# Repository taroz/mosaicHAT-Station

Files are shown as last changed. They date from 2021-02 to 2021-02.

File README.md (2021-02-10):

# mosaicHAT-Station
## Introduction
- [**mosaicHAT**](https://github.com/septentrio-gnss/mosaicHAT) + **GNSS antenna** + **Raspberry Pi** + **Touch display** + **Battery** + **Case**
- We use [Septentrio's mosaic-X5](https://www.septentrio.com/en/products/gnss-receivers/rover-base-receivers/receivers-module/mosaic) GNSS module which is a **low-cost** and **survey-grade** GNSS receiver
- This project is inspired by [mosaicHAT](https://github.com/septentrio-gnss/mosaicHAT) and extends it further. Thanks to the wonderful project [mosaicHAT](https://github.com/septentrio-gnss/mosaicHAT)!
- License: [Creative Commons Attribution Share-Alike License](https://creativecommons.org/licenses/by-sa/4.0/). and [Open Source HW](https://www.oshwa.org/definition/)  
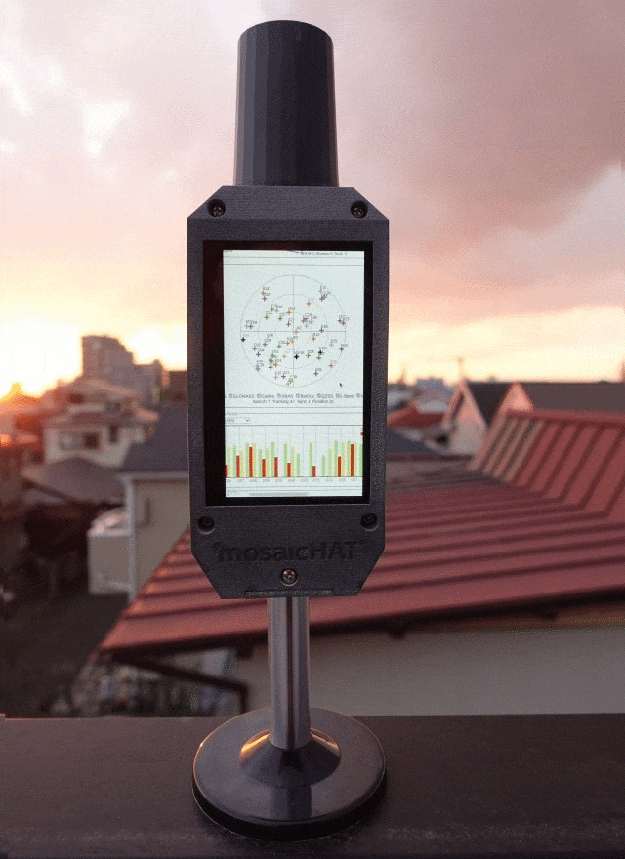
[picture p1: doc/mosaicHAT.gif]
 

## Features
- mosaicHAT Station has a touch display to display a web user interface of mosaic-X5 receiver. We can easily operate, monitor, and control the GNSS receiver.
- Compared to the original [mosaicHAT](https://github.com/septentrio-gnss/mosaicHAT), we added micro SD card and a log button, so you can easily store GNSS data as a GNSS reference or rover station.  
  [](https://www.youtube.com/watch?v=CmkE35LLup8)

## Board
- The design of the board is based on the original [mosaicHAT](https://github.com/septentrio-gnss/mosaicHAT).
- [KiCAD files](./board/KiCAD) and [PCB](./board/KiCAD/pcb)
- Micro SD card and log button have been added for data logging capability
- Bill of Materials (BOM) is [here](./board/mosaicHAT_BOM.xlsx)                                 
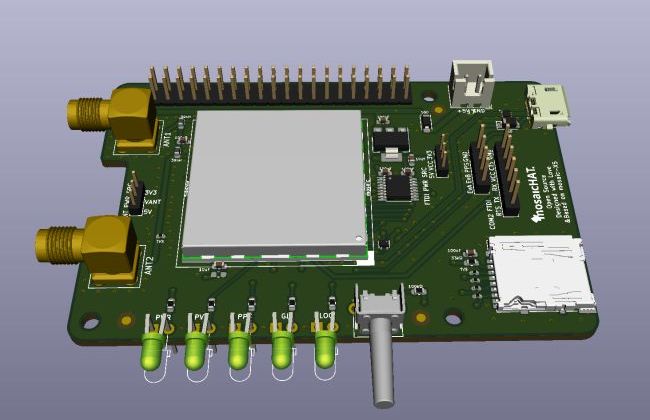
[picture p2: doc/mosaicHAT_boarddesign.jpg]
  

## Case
- You can create using 3D printer (STL data is [here](./case))
  - I used 3D printing service (by [Shapeways](https://www.shapeways.com/shops/tarosuzuki)) 
- A 5/8 nut can be fixed on the case, which can be attached to a pole or antenna mount for GNSS surveying.  
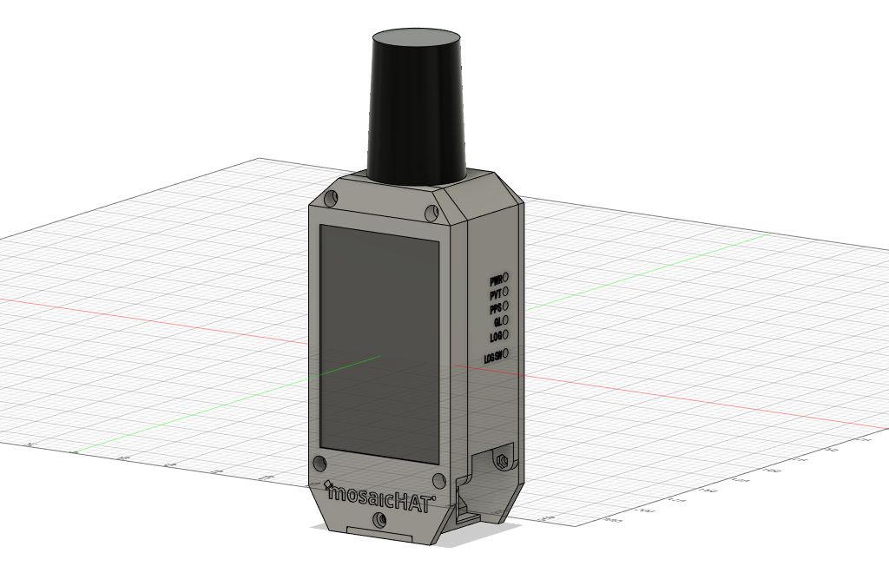
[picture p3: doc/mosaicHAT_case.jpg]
 

## How to assemble
- Parts list is [here](./case/parts_list.xlsx)  
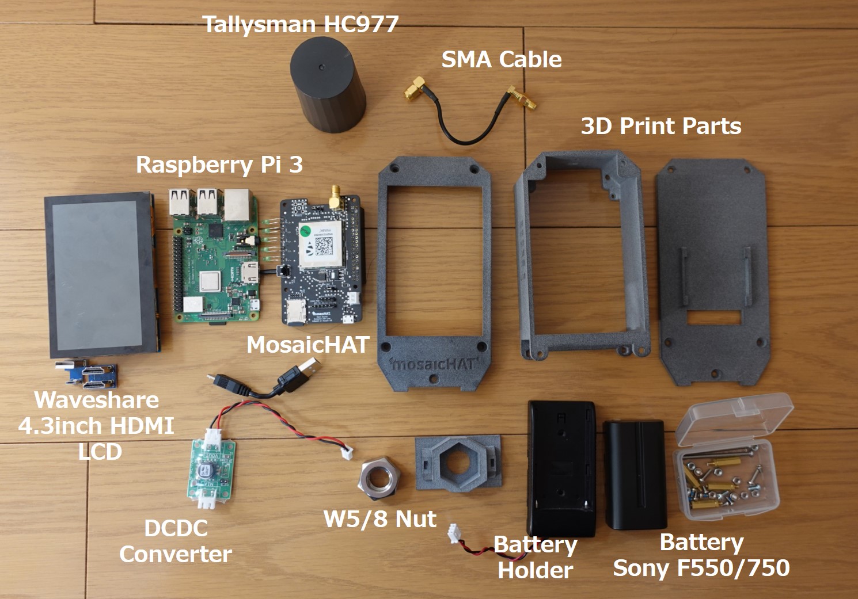
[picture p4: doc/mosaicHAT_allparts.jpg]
<p>

1. Mount the Raspberry Pi on the touch display. Then mount the mosaicHAT on the Rasberry Pi using the M2.5 18mm spacers and screws.   
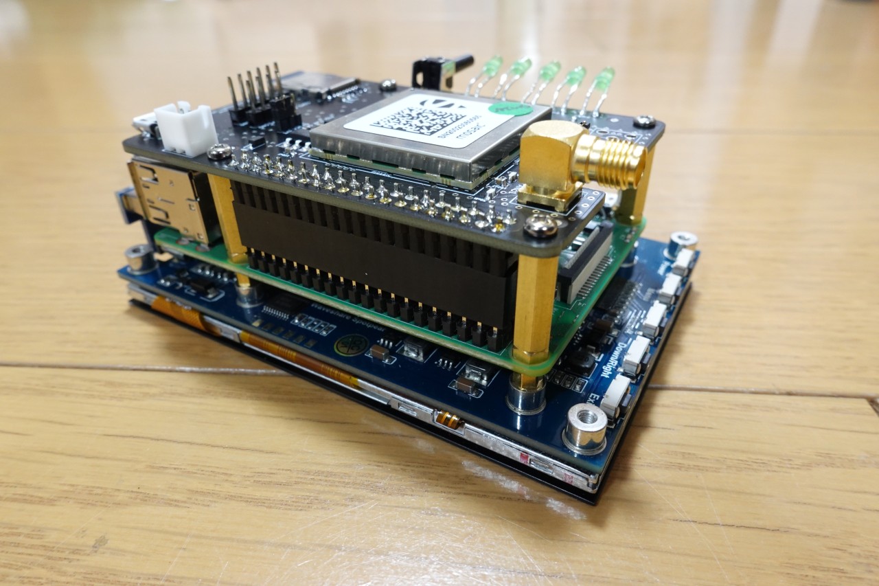
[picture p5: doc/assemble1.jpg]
<p>

2. Fix the GNSS antenna using the M2.5 screws. Connect the SMA cable. Mount the touch display on the case using the M2.5 screws.   
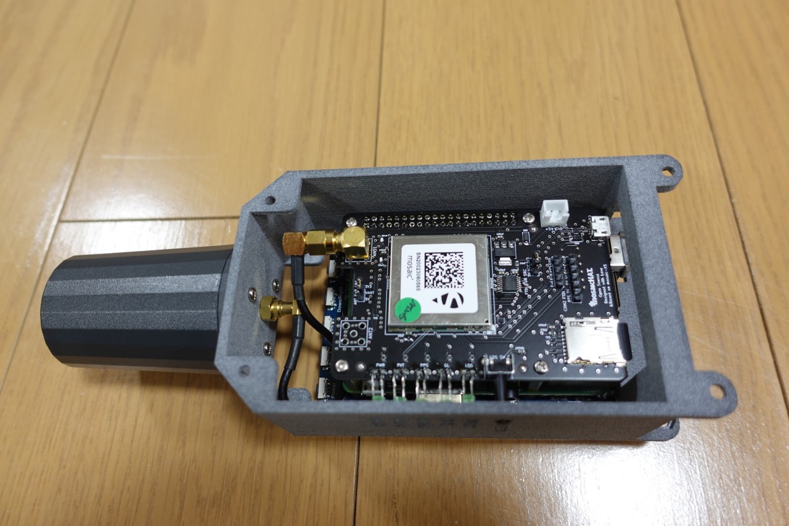
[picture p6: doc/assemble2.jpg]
<p>

3. Modify the battery holder to connect the DCDC converter to the battery. Fix the battery holder to the back plate. Then connect the power cable to the mosaicHAT. Fix the front plate using the M3 screws.  
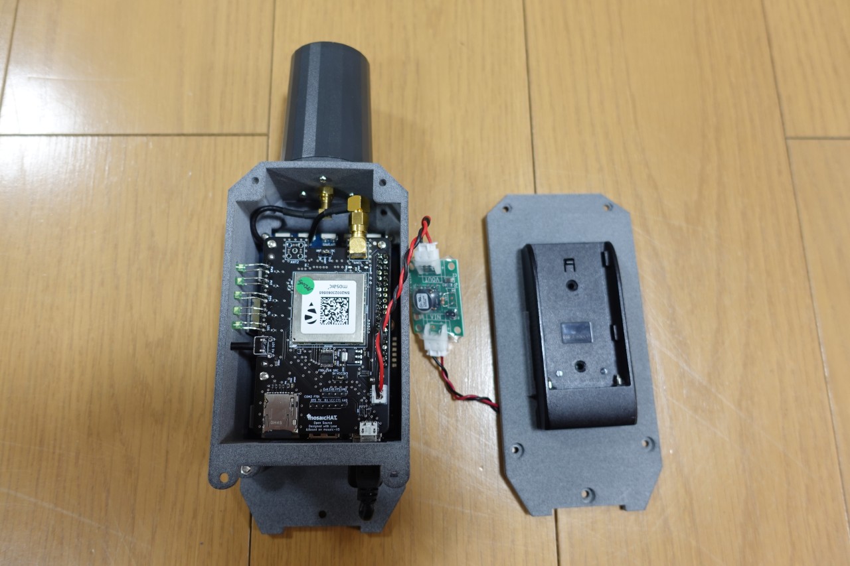
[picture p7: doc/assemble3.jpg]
<p>

4. Finally, fix the front and back plate using M3 50mm screws. Insert the W5/8 nut to bottom plate. Fix the bottom plate to the case.   
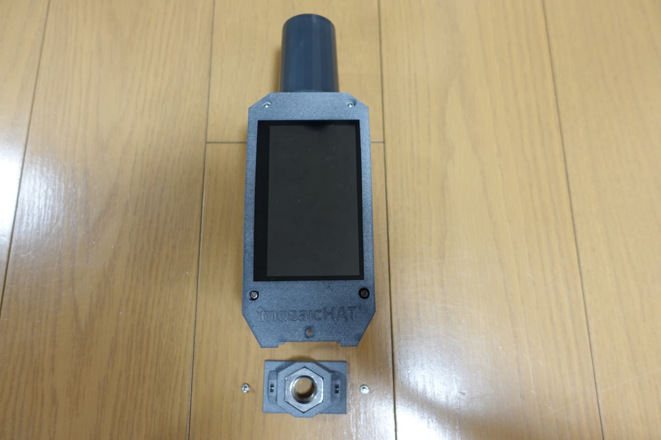
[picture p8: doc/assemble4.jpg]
<p> 

## Setup
### Install **Raspberry Pi OS** on Raspberry Pi
- See [here](https://www.raspberrypi.org/software/)

### Setup Toouch Screen
- mosaicHAT-Station uses [Waveshare 4.3inch HDMI LCD(B)](https://www.waveshare.com/4.3inch-hdmi-lcd-b.htm). See the [wiki](https://www.waveshare.com/wiki/4.3inch_HDMI_LCD_(B)) for setup instructions.

### Start web user interface of mosaic-X5
- mosaicHAT-Station uses Raspberry PI kiosk mode with Chromium for the web user interface.
- Install chromium.
```
sudo apt-get update && apt-get upgrade -y
sudo apt-get install chromium x11-xserver-utils
```
- Edit `/etc/xdg/lxsession/LXDE/autostart` and add the following lines:
```
@xset s off
@xset -dpms
@xset s noblank
@chromium --noerrdialogs --kiosk --incognito 192.168.3.1
```

### Make Raspberry Pi file system read-only
- Let's turn off the Raspberry Pi at any time without risk of damaging the operating system files.
- Run `sudo raspi-config`
- Choose "performance options" and then "Overlay File System". Choose "Yes" to enable it, and then choose "Yes" again to make the boot filesystem read-only.

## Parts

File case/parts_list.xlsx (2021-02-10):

Name | Quantity | Manufacturer | Product number | URL
GNSS antenna | 1 | Tallysman | HC977 | https://www.digikey.jp/products/ja?keywords=HC977
Touch display | 1 | Waveshare | 4.3inch HDMI LCD (B) | https://www.waveshare.com/4.3inch-hdmi-lcd-b.htm
Raspberry Pi 3 | 1 |  |  | https://www.digikey.com/en/products/detail/raspberry-pi/RASPBERRY-PI-3/6152799
Battery holder | 1 | Lilliput | F970 DSLR Battery Plate | https://lilliputdirect.com/lilliput-f970-battery-plate https://www.ebay.com/itm/LILLIPUT-Battery-Adapter-Base-Plate-F970-for-Sony-VX2100E-HVR-V1C-F330-/371421670220
Battery | 1 | Sony | NP-F550/570/750/770/970 | https://www.amazon.com/s?k=sony+f550
Power cable connector | 1 | JST | XHP-2 | https://www.digikey.com/en/products/detail/jst-sales-america-inc/XHP-2/555485
5V DCDC converter | 1 |  |  | https://www.digikey.jp/product-detail/ja/adafruit-industries-llc/1385/1528-2004-ND/6827137 https://www.ebay.com/itm/3A-UBEC-5V-6V-Full-Shielding-Antijamming-Switching-Regulator-New/332524267418
SMA cable | 1
micro USB cable | 1
W5/8 nut | 1
M3 Nut | 6
M3 50mm Screw | 2
M3 10mm Screw | 2
M3 6mm Screw | 4
M2.5 6mm Screw | 11
M2.5 Male x Female 18mm Spacer | 4

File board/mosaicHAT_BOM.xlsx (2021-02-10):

Reference | Quantity | Value | MPN | SPN | Digi-Key URL
C2 C6 | 2 | 10uF | CC0603KRX5R6BB106 | 311-1782-1-ND | https://www.digikey.com/product-detail/en/yageo/CC0603KRX5R6BB106/311-1782-1-ND/5195684
C1 C3 C4 C5 C8 | 5 | 100nF | CC0603KRX7R6BB104 | 311-4055-1-ND | https://www.digikey.com/product-detail/en/yageo/CC0603KRX7R6BB104/311-4055-1-ND/8025144
D1 D2 | 2 | MBRX120LF-TP | MBRX120LF-TP | MBRX120LF-TPMSCT-ND | https://www.digikey.com/product-detail/en/micro-commercial-co/MBRX120LF-TP/MBRX120LF-TPMSCT-ND/2041570
D4 D5 D6 D7 D8 | 5 | LED | 151031VS06000 | 732-5008-ND | https://www.digikey.com/en/products/detail/w%C3%BCrth-elektronik/151031VS06000/4489988
D9 D10 D11 D12 D13 | 5 | D_TVS | SESD0402X1BN-0010-098 | SESD0402X1BN-0010-098CT-ND | https://www.digikey.com/en/products/detail/littelfuse-inc/SESD0402X1BN-0010-098/5233522
FL1 | 1 | ECMF02-2AMX6 | ECMF02-2AMX6 | 497-10773-1-ND | https://www.digikey.com/product-detail/en/stmicroelectronics/ECMF02-2AMX6/497-10773-1-ND/2440287
J1 J2 | 2 | Conn_Coaxial | 132136 | ACX1232-ND | https://www.digikey.com/product-detail/en/amphenol-rf/132136/ACX1232-ND/1011909
J3 | 1 | USB_B_Micro | 1050170001 | WM1399CT-ND | https://www.digikey.com/product-detail/en/molex/1050170001/WM1399CT-ND/2350885
J4 | 1 | raspberrypi_hat_OX40HAT | PRT-14017 | 1568-1462-ND | https://www.digikey.com/en/products/detail/sparkfun-electronics/PRT-14017/6569366
J5 | 1 | Conn_01x04_Male | 61300411121 | 732-5317-ND | https://www.digikey.com/product-detail/en/w%C3%BCrth-elektronik/61300411121/732-5317-ND/4846827
J6 | 1 | Conn_01x06_Male | 61300611121 | 732-5319-ND | https://www.digikey.com/product-detail/en/w%C3%BCrth-elektronik/61300611121/732-5319-ND/4846833
J7 | 1 | Conn_01x02_Male | B2B-XH-A(LF)(SN) | 455-2247-ND | https://www.digikey.com/en/products/detail/jst-sales-america-inc/B2B-XH-A-LF-SN/1651045
J8 | 1 | Micro_SD_Card | DM3AT-SF-PEJM5 | HR1964CT-ND | https://www.digikey.com/en/products/detail/hirose-electric-co-ltd/DM3AT-SF-PEJM5/2533565
JP1 JP2 | 2 | Jumper_NC_Dual | 2PH1-03-UA | 2057-2PH1-03-UA-ND | https://www.digikey.com/product-detail/en/adam-tech/2PH1-03-UA/2057-2PH1-03-UA-ND/9830409
L1 L2 | 2 | 39nH | 744786139A | 732-6270-1-ND | https://www.digikey.com/product-detail/en/w%C3%BCrth-elektronik/744786139A/732-6270-1-ND/5087233
R1 R2 R3 R4 R5 | 5 | R330 | ERJ-3EKF3300V | P330HCT-ND | https://www.digikey.com/product-detail/en/panasonic-electronic-components/ERJ-3EKF3300V/P330HCT-ND/1746761
R6 | 1 | R33K | ERJ-3EKF3302V | P33.0KHCT-ND | https://www.digikey.com/en/products/detail/panasonic-electronic-components/ERJ-3EKF3302V/1746378
R7 | 1 | 100K | ERJ-U3RD1003V | 10-ERJ-U3RD1003VCT-ND | https://www.digikey.com/en/products/detail/panasonic-electronic-components/ERJ-U3RD1003V/12549460
U1 | 1 | mosaic-X5 | 410322 | 2771-410322-ND | https://www.digikey.com/en/products/detail/septentrio-inc/410322/12503897
U2 | 1 | LD1117AS33TR | LD1117AS33TR | 497-1228-1-ND | https://www.digikey.com/product-detail/en/stmicroelectronics/LD1117AS33TR/497-1228-1-ND/586228
U3 | 1 | SN74AVC4T245PW | SN74AVC4T245PWR | 296-18056-1-ND | https://www.digikey.com/product-detail/en/texas-instruments/SN74AVC4T245PWR/296-18056-1-ND/770944
U4 | 1 | SN74LVC1G126DRLR | SN74LVC1G126DRLR | 296-18013-1-ND | https://www.digikey.com/product-detail/en/texas-instruments/SN74LVC1G126DRLR/296-18013-1-ND/770528

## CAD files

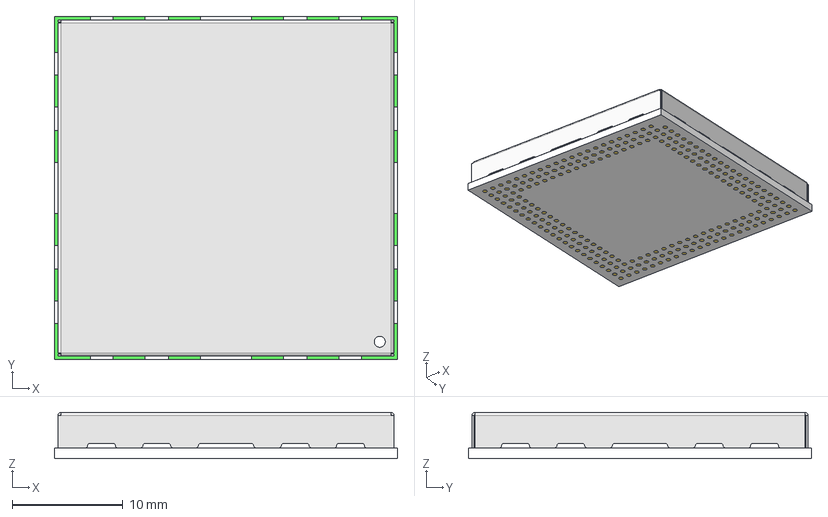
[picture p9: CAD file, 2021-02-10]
board/KiCAD/components/3D/mosaic3D.stp
31.0 x 31.0 x 4.18 mm
1V2_OUT_1
1V2_OUT_2
1V4_OUT_1
1V4_OUT_2
1V8_OUT
2V8_IN
2V8_OUT
ADC0
ADC1
ADC2
ANT_1
ANT_2
BOOT_MODE_0
CANRX
CANTX
CTS1
CTS2
CTS3
DIFFCOR_DET
DRDY/JTMS2
EVENTA
EVENTB
EVENTC
EXT_NINT_REF
GND1
GND002
GND10
GND003
GND100
GND101
GND102
GND103
GND104
GND105
GND106
GND107
GND108
GND109
GND11
GND110
GND111
GND112
GND12
GND113
GND13
GND114
GND14
GND115
GND15
GND116
GND16
GND117
GND17
GND118
GND18
GND119
GND19
GND120
GND2
GND121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

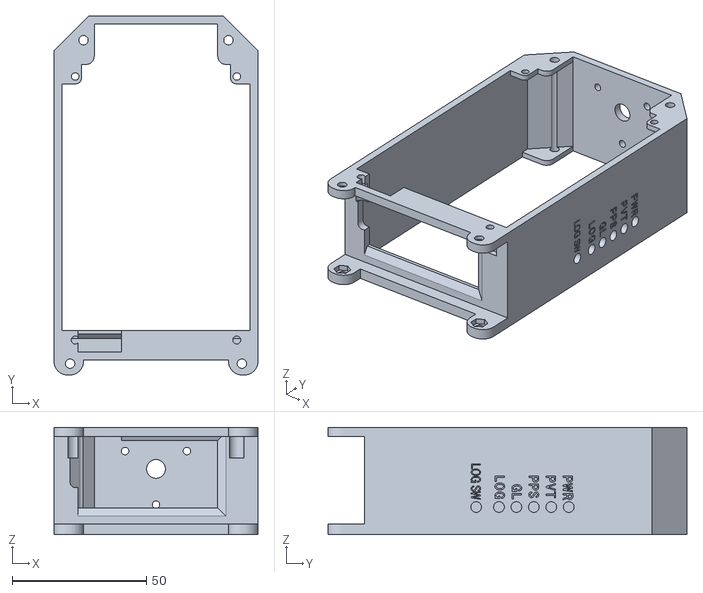
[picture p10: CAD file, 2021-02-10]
case/box_front.STL
76.0 x 133.7 x 40.0

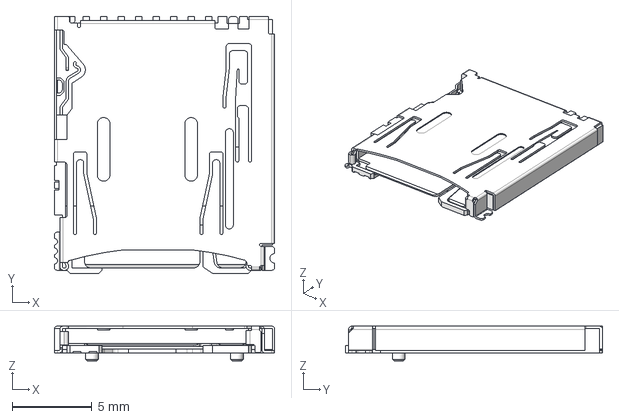
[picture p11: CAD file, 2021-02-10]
board/KiCAD/components/3D/DM3AT-SF-PEJ2M5.step
13.8 x 16.2 x 2.18 mm

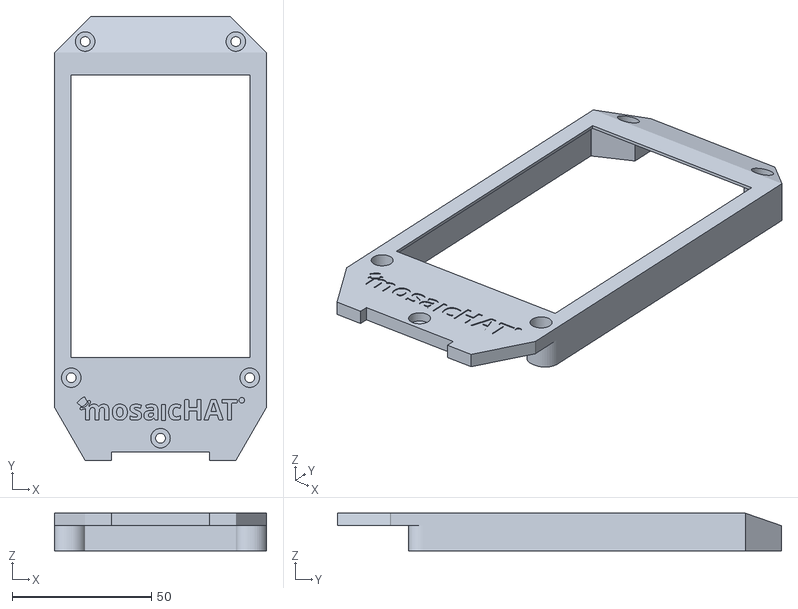
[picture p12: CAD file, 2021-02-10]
case/box_frontpanel.STL
76.0 x 159.2 x 13.5

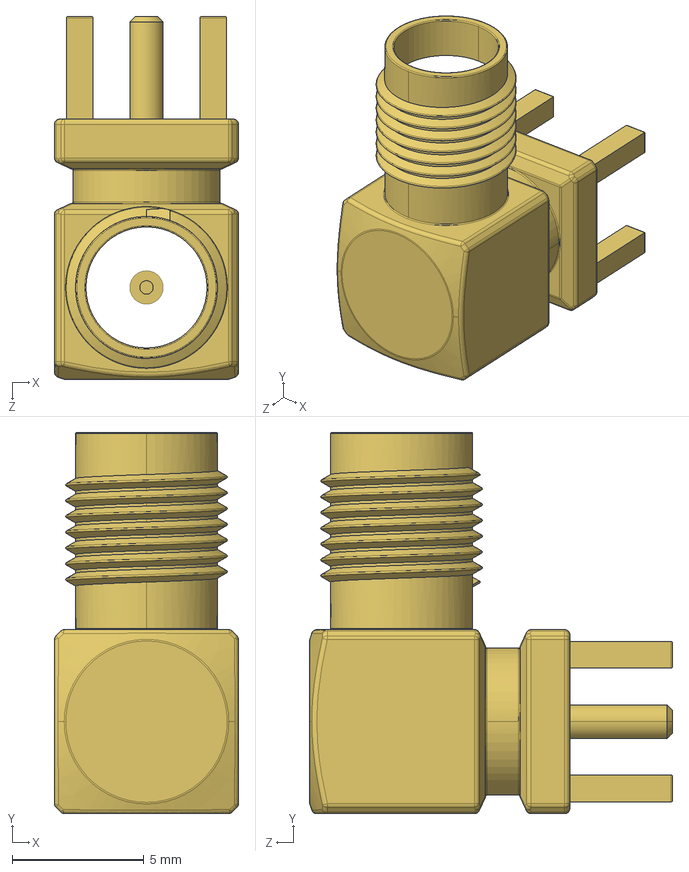
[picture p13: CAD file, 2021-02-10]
board/KiCAD/components/3D/SMA.STEP
7.00 x 14.5 x 13.8 mm

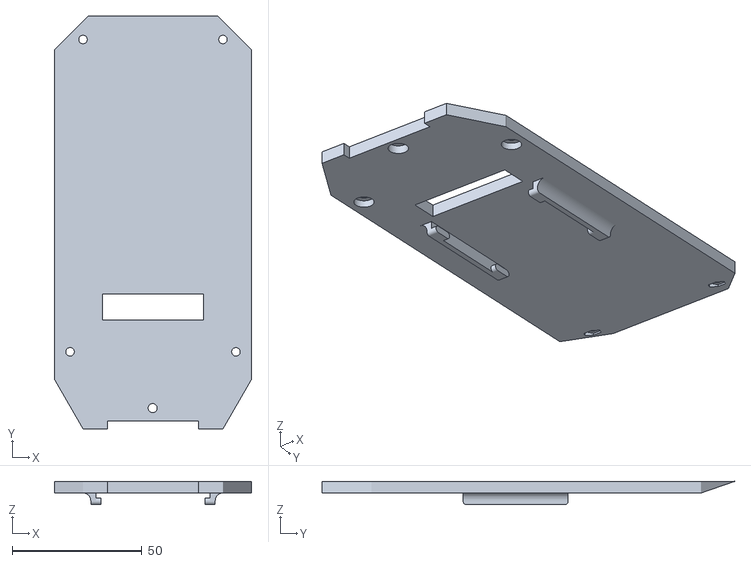
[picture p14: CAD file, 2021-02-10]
case/box_backpanel.STL
76.0 x 159.2 x 9.00

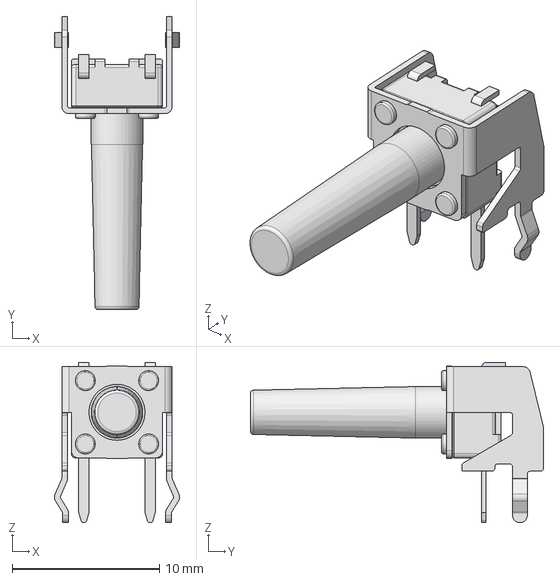
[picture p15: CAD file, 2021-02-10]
board/KiCAD/components/3D/SKHHNH.step
8.50 x 19.9 x 10.9 mm

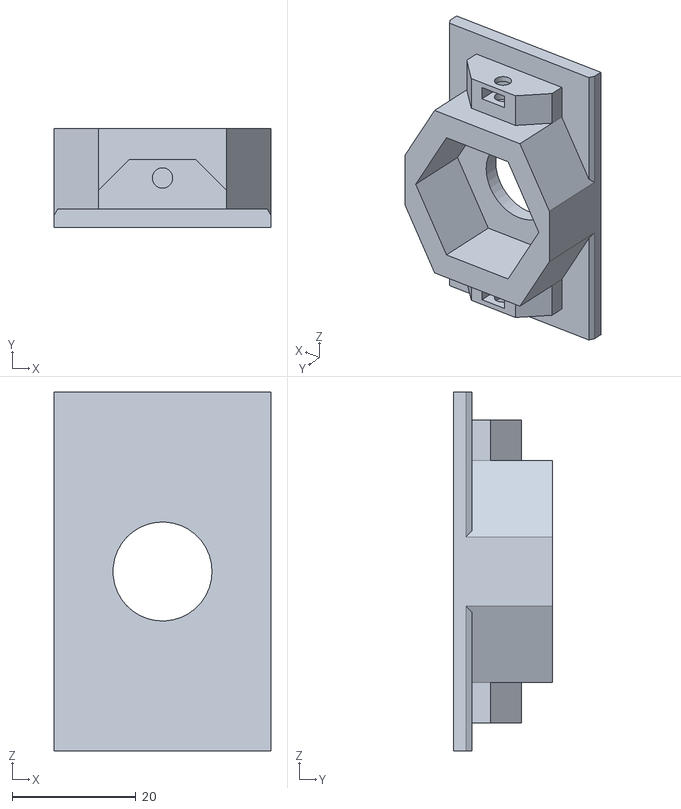
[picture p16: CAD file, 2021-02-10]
case/box_bottom.STL
35.0 x 16.0 x 58.0

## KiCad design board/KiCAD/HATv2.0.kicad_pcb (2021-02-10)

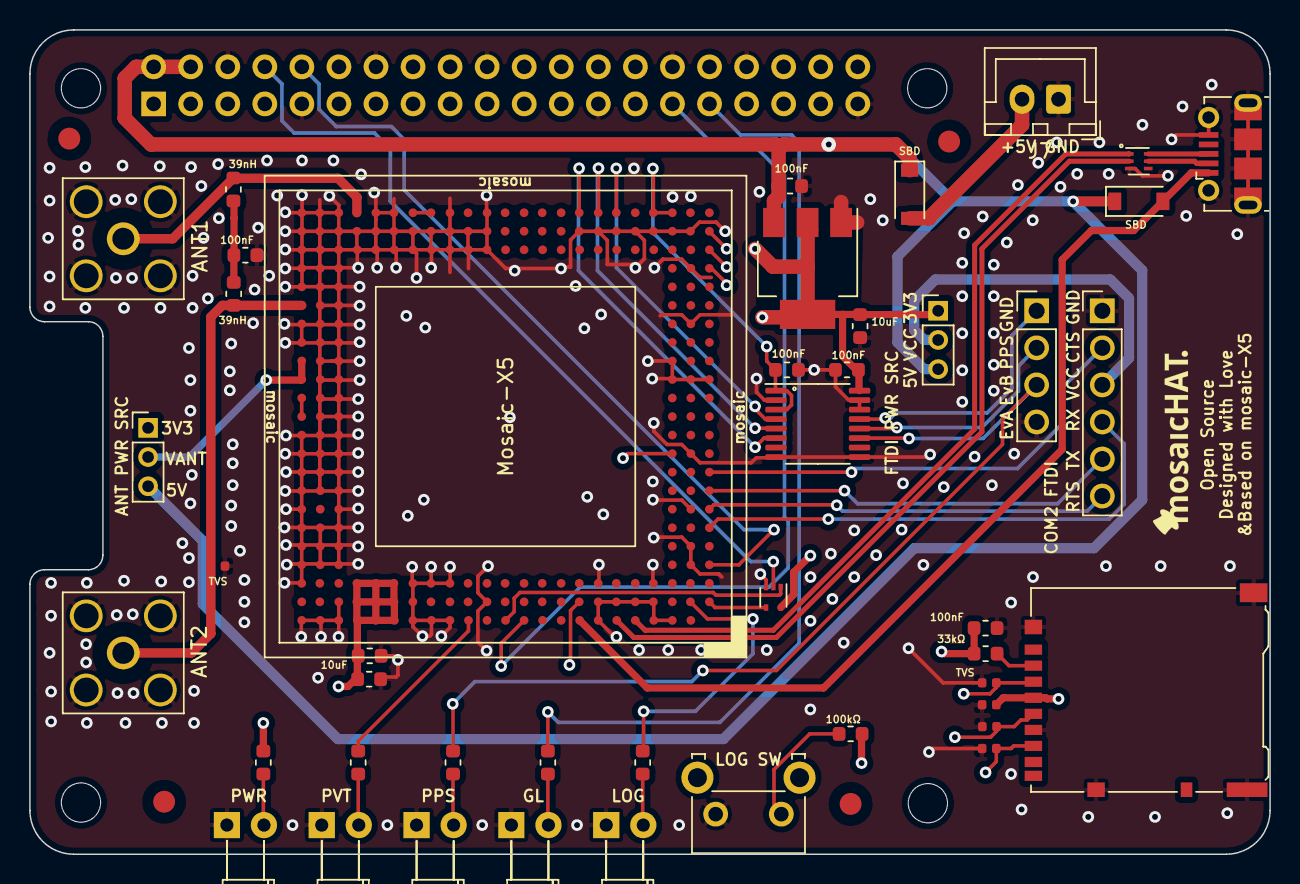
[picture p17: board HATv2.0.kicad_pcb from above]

Board: 4 copper layers, 85.0 x 56.5 mm, 49 parts (1 on the bottom side), 45 nets.

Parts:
C1, C3, C4, C5, C8: 100nF; C_0603_1608Metric
C2, C6: 10uF; C_0603_1608Metric
C7: un-assembled; C_0603_1608Metric
D1, D2: MBRX120LF-TP; D_SOD-123
D4, D5, D6, D7, D8: LED; LED_D3.0mm_Horizontal_O3.81mm_Z10.0mm
D9, D10, D11, D12, D13: D_TVS; R_0402_1005Metric
FID1, FID2, FID3, FID4: Fiducial; Fiducial_1.5mm_Mask3mm
FL1: ECMF02-2AMX6; ST_UQFN-6L_1.5x1.7mm_Pitch0.5mm
J1, J2: Conn_Coaxial; SMA_Amphenol_132203-12_Horizontal
J3: USB_B_Micro; USB_Micro-B_Molex-105017-0001
J4: raspberrypi_hat_OX40HAT; PinSocket_2x20_P2.54mm_Vertical
J5: Conn_01x04_Male; PinHeader_1x04_P2.54mm_Vertical
J6: Conn_01x06_Male; PinHeader_1x06_P2.54mm_Vertical
J7: Conn_01x02_Male; JST_XH_B2B-XH-A_1x02_P2.50mm_Vertical
J8: Micro_SD_Card_Det_Hirose_DM3AT; microSD_HC_Hirose_DM3AT-SF-PEJM5
JP1, JP2: Jumper_NC_Dual; PinHeader_1x03_P2.00mm_Vertical
L1, L2: 39nH; L_0603_1608Metric
R1, R2, R3, R4, R5: R330; R_0603_1608Metric
R6: R33K; R_0603_1608Metric
R7: R100K; R_0603_1608Metric
SW1: SW_Push; SW_Tactile_SKHH_Angled
U1: mosaic-X5; mosaic_X5
U2: LD1117AS33TR; SOT-223
U3: SN74AVC4T245PW; TSSOP-16_4.4x5mm_P0.65mm
U4: SN74LVC1G126DRLR; SOT-553

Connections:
+1V8: C4.1, U1.AC3, U1.AC4, U3.1, U3.3
+3V3: C2.1, C5.1, C6.1, C7.1, C8.1, D13.2, J8.4, JP1.1, JP2.1, R1.2, R6.2, R7.1, U1.A19, U1.A20, U1.B8, U1.B18, U1.B19, U1.B20, U1.C18, U1.C19, U1.C20, U2.2, U3.16, U4.5
+5V: C1.1, D1.1, D2.1, J4.2, J4.4, JP1.3, JP2.3, U2.3
/2V8: U1.M23, U1.N23
/ANT1: J1.1, L1.1, U1.AC20
/ANT2: D9.2, J2.1, L2.2, U1.V23
/D+: FL1.6, J3.3
/D-: FL1.5, J3.2
/EVENTA_1V8: U1.AC6, U3.4
/EVENTA_3V3: J5.1, U3.13
/EVENTB_1V8: U1.AC7, U3.5
/EVENTB_3V3: J5.2, U3.12
/External_5V: D2.2, J7.2
/FTDI_PWR: J6.3, JP2.2
/GPLED: R5.2, U1.A14
/LOGBUTTON: R7.2, SW1.1, U1.K3
/LOGLED: R4.2, U1.B2
/MODULE_RDY: U1.A12, U4.1
/MosaicCTS2: J6.2, U1.J1
/MosaicRTS2: J6.6, U1.G1
/MosaicRX1: J4.8, U4.2
/MosaicRX1_BufferOUT: U1.B1, U4.4
/MosaicRX2: J6.4, U1.F1
/MosaicTX1: J4.10, U1.D1
/MosaicTX2: J6.5, U1.H1
/PPSO_1V8: U1.AC8, U3.6
/PPSO_3V3: J5.3, R2.2, U3.11
/REF: U1.AC16, U1.AC17
/RPI_GP1: J4.31, R3.2
/SD_CLK: D11.2, J8.5, U1.AA1
/SD_CMD: D10.2, J8.3, U1.AB1
/SD_DAT0: D12.2, J8.7, U1.Y1
/USB_N: FL1.2, U1.A6
/USB_P: FL1.1, U1.A5
/USB_V: D1.2, J3.1, U1.A8
/VANT: JP1.2, U1.P23, U1.R23
/nRST_IN: J4.29, U1.A11
GND: C1.2, C2.2, C3.2, C4.2, C5.2, C6.2, C7.2, C8.2, D4.1, D5.1, D6.1, D7.1, D8.1, D9.1, D10.1, D11.1, D12.1, D13.1, FL1.3, J1.2, J2.2, J3.5, J3.6, J4.6, J4.9, J4.14, J4.20, J4.25, J4.30, J4.34, J4.39, J5.4, J6.1, J7.1, J8.6, J8.11, SW1.2, U1.A3, U1.A4, U1.A7, U1.A15, U1.A16, U1.A17, U1.A21, U1.A22, U1.A23, U1.AA13, U1.AA14, U1.AA15, U1.AA16, U1.AA17, U1.AA18, U1.AA19, U1.AA20, U1.AA21, U1.AA22, U1.AA23, U1.AB2, U1.AB3, U1.AB4, U1.AB5, U1.AB6, U1.AB7, U1.AB8, U1.AB13, U1.AB14, U1.AB15, U1.AB16, U1.AB17, U1.AB18, U1.AB19, U1.AB20, U1.AB21, U1.AB22, U1.AB23, U1.AC13, U1.AC15, U1.AC18, U1.AC19, U1.AC21, U1.AC22, U1.AC23, U1.B4, U1.B5, U1.B6, U1.B7, U1.B13, U1.B17, U1.B21, U1.C4, U1.C7, U1.C15, U1.C16, U1.C17, U1.C23, U1.D2, U1.D21, U1.D22, U1.D23, U1.E2, U1.E21, U1.E22, U1.E23, U1.F21, U1.F22, U1.F23, U1.G2, U1.G21, U1.G23, U1.H21, U1.H22, U1.H23, U1.J21, U1.J22, U1.J23, U1.K2, U1.K21, U1.K22, U1.K23, U1.L21, U1.L22, U1.L23, U1.M21, U1.M22, U1.N21, U1.N22, U1.P1, U1.P2, U1.P3, U1.P21, U1.P22, U1.R3, U1.R21, U1.R22, U1.T21, U1.T22, U1.T23, U1.U2, U1.U21, U1.U22, U1.U23, U1.V21, U1.V22, U1.W21, U1.W22, U1.W23, U1.Y2, U1.Y21, U1.Y22, U1.Y23, U2.1, U3.2, U3.8, U3.9, U3.14, U3.15, U4.3
unnamed: C3.1, L1.2, L2.1
unnamed: D4.2, R1.1
unnamed: D5.2, R2.1
unnamed: D6.2, R3.1
unnamed: D7.2, R4.1
unnamed: D8.2, R5.1
unnamed: J8.2, R6.1

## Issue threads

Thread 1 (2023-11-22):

Ethernet capability

jiargei, 2023-11-22:
Dear @taroz

I know that the mosaic chip has Network capability too. Since I'm not an electrical engineer and don't know how to use KiCAD are you any how interested in adding pins for the ethernet?

Within the HardwareManual at section "4 Pinout and I/O Description" and "4.5 Ethernet" the pins are listed resp. shown. Do you think that it's possible to add this?

Which provider did you use to build the pcb and assembling?

kind regards

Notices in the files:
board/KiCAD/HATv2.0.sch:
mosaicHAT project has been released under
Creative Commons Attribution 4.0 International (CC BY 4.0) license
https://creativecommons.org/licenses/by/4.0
